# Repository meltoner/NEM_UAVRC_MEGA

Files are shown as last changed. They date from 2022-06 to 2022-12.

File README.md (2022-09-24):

# NEM UAVRC MEGA

NEM Unmanned Vehicle Remote Controlled software on Arduino Mega 2550 pro

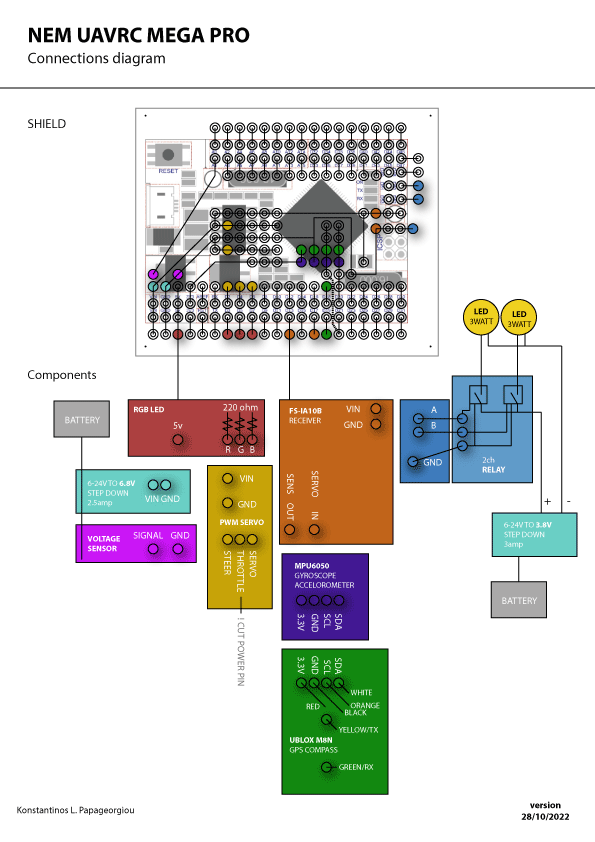
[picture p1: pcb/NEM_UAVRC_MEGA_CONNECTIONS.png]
Shield diagram


## Software Features :

- Software utilises an MPU6050, GPS, Servo, ESC, magnetometer and an amphidromous remote control, powered by an Arduino mega pro.
- Sensors and actuators are all in classes
- Implement seven tasks execution frequencies
- Adaptive steering based on target degrees
- Boots ESC motor and applies a non liner transfer function to the speed remote input
- Computes degrees heading at boot time, used as an offset for the MPU degree heading
- Derives distance and degrees from a target GPS LAT LOT
- Return to target GPS / home on signal loss or switch D
- Adaptive speed while approaching target
- Detection of low battery and return to home
- Transmits distance of vehicle from target GPS
- Lowers throttle while turning
- RGB Led indicator - no GPS red, GPS lock - green, return to home blue
- Variable led blinking indicator
- Target GPS restoration, after power loss

## Hardware

Sensors :

- GPS : [Ublox M8N with compass](https://www.aliexpress.com/item/4001267138914.html)
- Magmetometer : M8n's HMC5883
- MPU : [MPU6050](https://www.aliexpress.com/item/32340949017.html)
- Receiver  [flysky F9-ia10b](https://www.aliexpress.com/item/1005002151189775.html)
- Voltage sensor 0-25v [MH-electronic](https://www.hellasdigital.gr/electronics/sensors/current-sensors/voltage-sensor-module-for-robot-arduino-dc-0-25-v/)

Components : 

- [Arduino mega pro 2560](https://www.aliexpress.com/item/1005002828018807.html)
- Transmitter [flysky FS-I6X](https://www.aliexpress.com/item/1005002086903692.html)
- DC to DC Step down [3 amp](https://grobotronics.com/dc-dc-step-down-1.3-35v-3a.html)
- DC to DC Step down ultra small [2.5 amp](https://www.aliexpress.com/item/32880983608.html)
- Solid state 2 channel relay [SSR 5V 2A - 2 Channel](https://grobotronics.com/relay-module-ssr-5v-2a-2-channel.html)
- High Power Led 3W - [Cold White](https://grobotronics.com/high-power-led-3w-cold-white-emitter-2.html)
- High Power Led 3W - [Green](https://grobotronics.com/high-power-led-3w-green-emitter-2.html)
- RGB LED [anode](https://grobotronics.com/led-clear-5mm-rgb-common-anode.html)
- 3X 220Ohm [resistance](https://grobotronics.com/resistor-1-4w-metal-1-220ohm.html)
- [NEM Battery LI-PO 7.4v 2500mAh](http://www.nemhobby.com/nem-li-po-7-4v-2500mah-20c-500-charges-p31134.html)
- [Male Pin headers](https://grobotronics.com/pin-header-1x40-male-2.54mm-black-long-centered.html)
- [Female Pin headers](https://grobotronics.com/pin-header-1x10-female-2.54mm.html)
- [Cable with compatible JST BEC](http://www.nemhobby.com/plug-extension-silicone-wire-10cm-with-jst-gold-connectors-male-p34787.html)
- [XT60 Gold Connectors - Set](http://www.nemhobby.com/xt60-gold-connectors-set-p32855.html)
- [T-Plug Gold Connector - Male](http://www.nemhobby.com/t-plug-gold-connector-male-p34785.html)
- [Ribbon cable](https://grobotronics.com/ribbon-cable-28awg-0.081mm2-14-wire.html)
- Red, black wire
- PCB Etching agent
- [1mm drills](https://www.ergaleiogatos.gr/shop/trypania-sidirou-hss-bluespot-set-10-temachion/)
- [Copper plate](https://grobotronics.com/prototyping-copper-board-100x75mm-0.8mm-35um-2-layer.html)
- [pilot marker](https://goniasou.gr/pilot-markadoros-anexitilos-twin-marker-begreen/)
- NEM PCB Shield

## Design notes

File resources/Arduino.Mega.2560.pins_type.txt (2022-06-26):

Analog pin 0
Analog pin 1
Analog pin 2
Analog pin 3
Analog pin 4
Analog pin 5
Analog pin 6
Analog pin 7
Analog pin 8
Analog pin 9
Analog pin 10
Analog pin 11
Analog pin 12
Analog pin 13
Analog pin 14
Analog pin 15
Digital pin 0 (RX0)
Digital pin 1 (TX0)
Digital pin 2 (PWM)
Digital pin 3 (PWM)
Digital pin 4 (PWM)
Digital pin 5 (PWM)
Digital pin 6 (PWM)
Digital pin 7 (PWM)
Digital pin 8 (PWM)
Digital pin 9 (PWM)
Digital pin 10 (PWM)
Digital pin 11 (PWM)
Digital pin 12 (PWM)
Digital pin 13 (PWM)
Digital pin 14 (TX3)
Digital pin 15 (RX3)
Digital pin 16 (TX2)
Digital pin 17 (RX2)
Digital pin 18 (TX1)
Digital pin 19 (RX1)
Digital pin 20 (SDA)
Digital pin 21 (SCL)
Digital pin 22
Digital pin 23
Digital pin 24
Digital pin 25
Digital pin 26
Digital pin 27
Digital pin 28
Digital pin 29
Digital pin 30
Digital pin 31
Digital pin 32
Digital pin 33
Digital pin 34
Digital pin 35
Digital pin 36
Digital pin 37
Digital pin 38
Digital pin 39
Digital pin 40
Digital pin 41
Digital pin 42
Digital pin 43
Digital pin 44 (PWM)
Digital pin 45 (PWM)
Digital pin 46 (PWM)
Digital pin 47
Digital pin 48
Digital pin 49
Digital pin 50 (MISO)
Digital pin 51 (MOSI)
Digital pin 52 (SCK)
Digital pin 53 (SS)

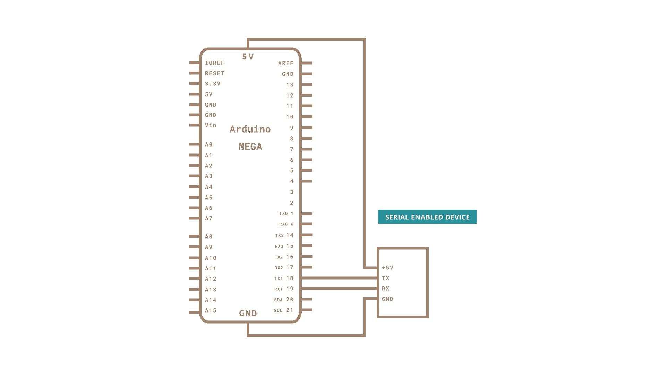
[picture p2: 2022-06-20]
resources/mega_serials_schematic.png

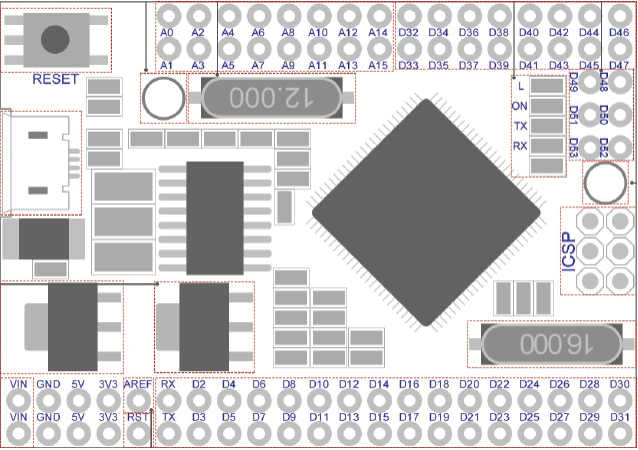
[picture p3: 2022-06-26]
pcb/arduino_mega_2550_pro_$3dm$Embedded$_6498F50D.png

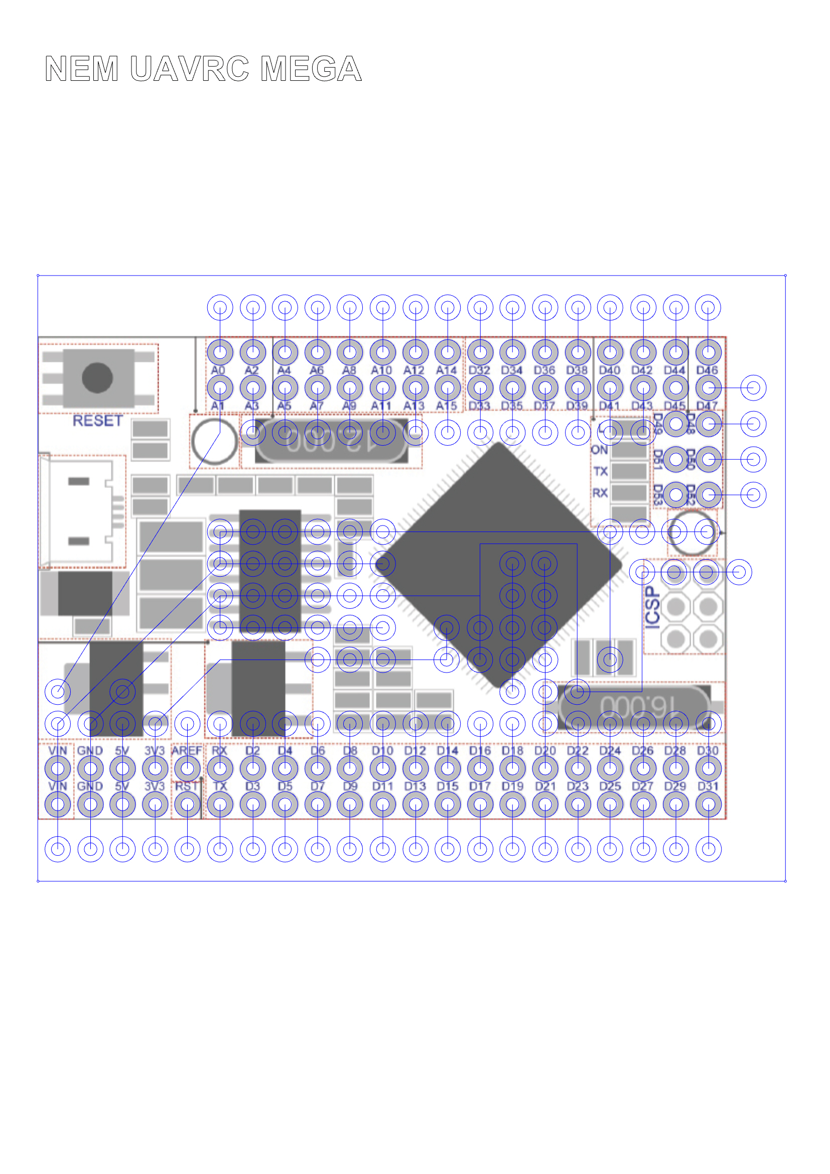
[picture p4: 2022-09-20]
pcb/pcb.jpg

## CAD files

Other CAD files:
pcb/NEM_UAVRC_MEGA_shield_holes.3dm

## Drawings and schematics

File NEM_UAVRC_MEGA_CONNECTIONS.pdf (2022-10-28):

## SHIELD

# NEM UAVRC MEGA PRO

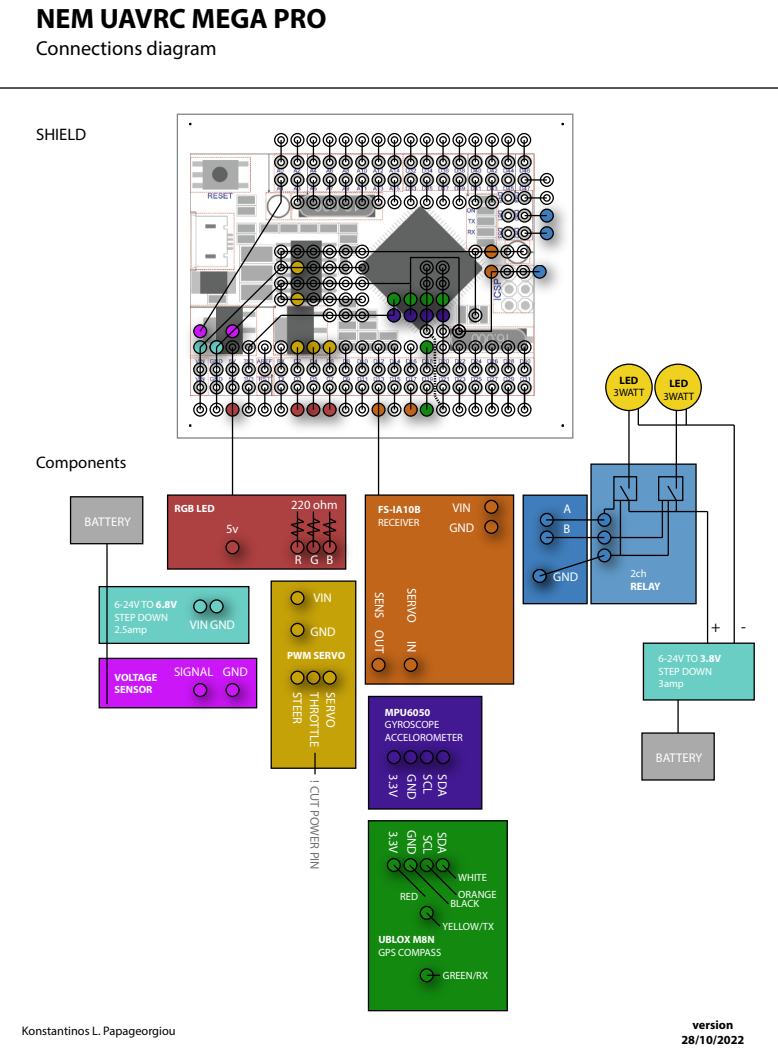
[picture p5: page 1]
RGB LED; 220 ohm; VIN; SIGNAL; OUT; LED 3WATT; GND; SCL; SDA; SENS; SERVO; BATTERY; Components; Connections diagram; STEER; 6-24V TO 6.8V STEP DOWN 2.5amp; VOLTAGE SENSOR; MPU6050 GYROSCOPE ACCELOROMETER; PWM SERVO; FS-IA10B RECEIVER; UBLOX M8N GPS COMPASS; 6-24V TO 3.8V STEP DOWN 3amp; ORANGE BLACK; YELLOW/TX; GREEN/RX; RED; WHITE; 2ch RELAY; version 28/10/2022 Konstantinos L. Papageorgiou

THROTTLE ! CUT POWER PIN

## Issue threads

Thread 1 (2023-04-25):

Firmware for flysky

infernos90, 2023-04-25:
Hello, is it necesary to flash a specific firmware for flysky?
Is it posible to save a waypoints from transmitter?

meltoner, 2023-04-25:
Hi we do not use a specific firmware for flysky. we use as from the factory.
you can save one way point from the transmitter.

infernos90, 2023-04-30:
I know I'm annoying but I apologize.  I am excited about your project and would like to know if you can help me adapt it for a bait boat.  I would like to know if you can modify the arduino code so that you save 2-3 gps coordinates and when the boat gets there it executes a servo open command.  thank you and much respect.

infernos90, 2023-04-30:
Something like this https://youtu.be/YnJC4XFGN8c

meltoner, 2023-04-30:
Sure you can modify the code since it already includes how to reach one target. Interchanging the existing target with an array would be the key modification. how would you enter the gps coords? currently the logic is to get feadback from the gps so you know you have reached the target position and then you can open the bait.

infernos90, 2023-04-30:
"how would you enter the gps coord?"
No. It is possible to save from transmitter? Exemple when i riched the specific point, switch button channel 8 to save it?

meltoner, 2023-05-01:
Well that how its currently done. It first derives the starting point on boot up, but you can update home using the switch.
Do you have some island you want to avoid and you need multiple ?

infernos90, 2023-05-01:
For bait boat is necesary to save one home point and  few waypoints (2-3 is enough). Another question is if it possible to return the boat constantly without this pause for searching gps.

meltoner, 2023-05-01:
inferno anything is possible. feel free to expand the code at your convenience

infernos90, 2023-05-01:
first i need to learn c++... I am good only on soldering and building things... Thanks

meltoner, 2023-05-01:
i see inferno, maybe in the future i wont have so many in my plate and i could do it for you, or you may soon be in a position to do it! talk again!

infernos90, 2023-05-01:
Ok. Thanks. I subscribed you!

oldcityboy, 2024-10-12:
> Yem botu için bir ev noktası ve birkaç rota noktası (2-3 yeterlidir) kaydetmek gerekir. Bir diğer soru ise gps araması için bu duraklama olmadan botu sürekli döndürmenin mümkün olup olmadığıdır.

Hello, have you installed GPS autopilot and location marking inside the feeding boat?

meltoner, 2024-10-13:
have a read at the documentation

Closed 2023-04-25.

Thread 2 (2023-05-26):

Brushless ESC

infernos90, 2023-05-26:
Hello again. This work with brushless ESC?

meltoner, 2023-05-26:
yep

infernos90, 2023-05-26:
I was unable to arm the motor.

meltoner, 2023-05-26:
can you send me a picture of what you have done?

meltoner, 2023-05-26:
I would guess that maybe your connections are wrong, or the pin was set incorrectly.
For your info, the arm command is visible within the Throttle::setup(Context &_context) function see lines 18 and 19.
If you still have issues the best approach is to make a hello world example that only arms the motor and then spins it. once you achieve that you ll be able to see what was out of place in your code currently.

infernos90, 2023-05-26:
>

I assambled everything to a testing board. Tomorrow i will soldering everything and testing again. This part " (byte pin){
  _pin = pin;" from the code, is attributing automatically pin for every component

meltoner, 2023-05-26:
yes Throttle is parametrised on its pin, on UAVRC_MEGA.ino on line 33 you see Throttle throttle(2); this means that the esc should be put on D2

infernos90, 2023-05-26:
Ok, i understand.
What is the role of the "hook" in this project?

meltoner, 2023-05-26:
for fishing, drops the hook

infernos90, 2023-05-26:
What switch is for activating the hook?

vin., 26 mai 2023, 23:27 meltoner ***@***.***> a scris:

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

meltoner, 2023-05-26:
give it a try to find it on your own, you would search where the object hook is used.
if you can't find it, ill check it out for you

infernos90, 2023-05-27:
Switch B!

meltoner, 2023-05-27:
bravo inferno90 !

infernos90, 2023-05-27:
Look at this video. Only beeping from ESC and not arming.

https://youtu.be/g7Y91y6uPNA

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

meltoner, 2023-05-28:
nice work !!

i noticed that you haven't actually connected the esc to the board. it should be connected to the arduino instead of the flysky receiver have a look at some more detailed photos of the fabrication in the attached pdf.

its flysky -> arduino -> esc, servo
 (see the horizontal ibus cable (in,out) do slot them in the vertical slots)

[phase2_prototype_fabrication.pdf](https://github.com/meltoner/NEM_UAVRC_MEGA/files/11584009/phase2_prototype_fabrication.pdf)

In case its helpful i had also made a board like a shield so you can detach the whole thing. Although it may not be that obvious the first image in the repository shows the "board".

I also understand that you have went to assemble everything in one go, which is also what i usually do and then get a hell of debugging in view of one just error. the proper way to do it is incrementally, i.e. first verify X then verify y and etc. i also noticed that you are using a regular led instead of an rgb. off course its not mandatory.

just take it step by step and it would also be very helpfull to also use the serial cable to print out on terminal the various phases the board undergoes during initialization.

since you have made this progress i am confident you with few careful iterations you reach the desired goal.

insane work! bravo

infernos90, 2023-05-28:
Maybe you didn't see correctly, but ESC is connected to pin D2. In the video i changed ESC connection to pin D2, D4 și D6 and not arming....

meltoner, 2023-05-28:
mmm yes, i see in the video its different from the photos.
1. note that the arm can happen if the motor takes power and the arduino takes power simultaneously. arming happens within the first power up.

2 what about the other stuff, does the servo move while connected to d4, i didn't see a movement in the video ?
3 how about if you connect a usb to read up the serial? context.apply(); prints out almost all internal details, so you can see can checkout what work and what doesn't work.
4. having done 3 you can also add in the setup function of each module a print like Serial.print("setting up mpu"); so you can see if something fails which would pauses the boot up sequence all together. for example the mpu might say while(mpuisnotacailable); wait until it is.

infernos90, 2023-05-28:
I have fs-ia6b receiver and in your project is fs-ia10b receiver. Maybe it is a problem?

meltoner, 2023-05-28:
probably not, since it has an ibus slots..

do you know how to see the serial print out of the board ? to see whats is happening? as you after you upload the firmware just open up serial from arduino cli

infernos90, 2023-05-28:
![Uploading IMG20230528130155.jpg…]()

infernos90, 2023-05-28:
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

meltoner, 2023-05-28:
ok its should print more after the mpu so something is interrupted, though mpu is after the throttle. in any case

after the mpu its the mag, i see no printout there in its setup, next is hook, ok next is gps. the gps setup function does print Serial.print("setup"); so since i do not see it in the print i understand that something before it fails. this apears to be the mag.
```
  mpu.setup(context);           rgb.apply_color(3);  delay(500); // yellow
  mag.setup(context);           rgb.apply_color(4);  delay(500);
  hook.setup(context);  
  gps.setup(context);           rgb.apply_color(5);  delay(500);
  steer.setup(context); 
  battery.setup(context);
  home.setup(context);          rgb.apply_color(6);  delay(500);
  invoker.setup(context);
  relayA.setup(context);
  relayB.setup(context);        context.color = 3;  delay(500);
  remote.setup(context);
  telemetry.setup(context);
```

 Add there in mag more print out to see if it passes from that place. although these are after the throttle pass over everything to ensure all components are setuped properly. At the end of the program setup sequence, its should enter in the loop sequence and every 1 second it should reflect all sensors readings via the context.apply()

infernos90, 2023-05-28:
I connected SCL and SDA from mpu and mag to same pin. It is correct?

meltoner, 2023-05-28:
i think its not. According to the diagram , https://github.com/meltoner/NEM_UAVRC_MEGA/blob/main/pcb/NEM_UAVRC_MEGA_CONNECTIONS.png i see in the green area, that the magnetometer/compass is assigned to an RX pin.

meltoner, 2023-05-28:
the 15th outer pin counting from the left as i see the diagram

infernos90, 2023-05-28:
According to your diagram, SDA from mpu and mag is connected both to pin 20 and SCL from mag and mpu connected both to pin 21

infernos90, 2023-05-28:
> the 15th outer pin counting from the left as i see the diagram

This pin is for gps module  according to your diagram.

meltoner, 2023-05-28:
my gps has a magnetometer embedded. that is why the look as the same module.
in the image the top pins are for the gps and the bottom is for the compass

meltoner, 2023-05-28:
Yes you are correct, as you stated above. gps uses the serial the mpu and mag use sda and scl. checked it out in haste
About how to debug the remedy is to add Serial.print and see where the execution stops to determine where is the problem.
for example you have to find out which was the last module starting to initialize but didn't complete.

infernos90, 2023-05-28:
I found a problem: it shows "begin mpu, do not move, succes" without mpu and mag connected. Only module connected is gps

infernos90, 2023-05-28:
Maybe is a problem with pins adress attribution

meltoner, 2023-05-28:
strange i would expect it to fail without them connected. ..

infernos90, 2023-05-28:
I tried with a simple servo motor. Not working. Maybe is not something correct in code.

meltoner, 2023-05-29:
no everything has been fabricated and tested multiple times with videos. i can't project what is off could be just a wire missed, but one would have to test each thing carefully until discovers what is off. In theory i would test each component you have on its own one by one.

meltoner, 2023-05-29:
inferno it just happens that i will be reproducing a 3rd time the project within the next month, nearly identical setup, so i will be re-passing the same steps you have and in case i find any deviation in the plans ill let you know.

infernos90, 2023-05-29:
Ok. Thank you.

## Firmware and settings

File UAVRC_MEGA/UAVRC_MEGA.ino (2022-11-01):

//
// @author : Konstantinos L. Papageorgiou - 2022 - kp at rei.gr
// @repo: https://github.com/meltoner/NEM_UAVRC_MEGA
//
// # NEM UAVRC MEGA
// 
// NEM Unmanned Vehicle Remote Controlled software on Arduino Mega 2550 pro
//

#include "Context.h"
#include "Invoker.h"

#include "Mag.h"
#include "Gps.h" 
#include "Mpu.h" 
#include "Steer.h"
#include "hook.h"
#include "Throttle.h"
#include "Remote.h"
#include "Telemetry.h"
#include "Home.h"
#include "RGB.h"
#include "Battery.h"
#include "Relay.h"

Context context(0);
Invoker invoker(0);

Mag mag(0);
Gps gps(0);
Mpu mpu(0);

Throttle throttle(2);
Steer steer(4);
Hook hook(6);

Remote remote(0);
Telemetry telemetry(0);

Home home(0);
RGB rgb(0);
Battery battery(0);

Relay relayA(50, 0);
Relay relayB(52, 1);

//-----------------------------------------

void setup() {
  context.setup();  
  rgb.setup(context);
  throttle.setup(context);      rgb.apply_color(1); // green
  delay(3000);                  rgb.apply_color(2); // blue
  
  mpu.setup(context);           rgb.apply_color(3);  delay(500); // yellow
  mag.setup(context);           rgb.apply_color(4);  delay(500); 
  hook.setup(context);          
  gps.setup(context);           rgb.apply_color(5);  delay(500);
  steer.setup(context);         
  battery.setup(context);       
  home.setup(context);          rgb.apply_color(6);  delay(500);
  invoker.setup(context);
  relayA.setup(context);
  relayB.setup(context);        context.color = 3;  delay(500);
  remote.setup(context);        
  telemetry.setup(context);

}

//-----------------------------------------

void apply_interval_0(){
  mag.apply();
  telemetry.apply();
  mpu.apply();
}

void apply_interval_1(){
  remote.apply();
  steer.apply();
  throttle.apply();
}

void apply_interval_2(){
  gps.apply();
  telemetry.run();
  home.apply();
  rgb.apply();
  telemetry.run();
  relayA.apply();
  relayB.apply();  
}

void apply_interval_3(){
  context.apply();
  hook.apply();
}

void apply_interval_4(){
  relayA.toggle();
}

void apply_interval_5(){
  battery.apply();
}

void apply_interval_6(){
  if(context.toHomeActive)
    mag.updateMagOffset();

  gps.testStationary();
}

void apply_interval_7(){
  home.bursts();
}


//-----------------------------------------

void run_invoker(int i){
    switch(i){
      case 0: apply_interval_0(); break;
      case 1: apply_interval_1(); break;
      case 2: apply_interval_2(); break;
      case 3: apply_interval_3(); break;
      case 4: apply_interval_4(); break;
      case 5: apply_interval_5(); break;
      case 6: apply_interval_6();break;
      case 7: apply_interval_7();break;
      case 100: break;
    }
}

//-----------------------------------------

void loop(){
  mpu.update();
  telemetry.run();
  int actionIndex = invoker.apply();
  while(actionIndex != 100){
    run_invoker(actionIndex);
    telemetry.run();
    actionIndex = invoker.apply();
  } 
}

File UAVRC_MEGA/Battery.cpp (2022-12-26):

/*
  Battery.h - Library for warping the functions controlling the Battery power levels
  Author - Konstantinos Papageorgiou kp at rei.gr 2022 
*/

#include "Arduino.h"
#include "Battery.h" 
#include "Context.h"

Battery::Battery(byte pin){}

void Battery::setup(Context &_context){
  context = &_context;
  measureVoltage();

  

  apply();  
}

float Battery::measureVoltage(){
  context->voltage =  (analogRead(0) / 40.92);
  context->voltage = context->voltage * 0.735 ;
  return context->voltage;
}

void Battery::apply(){
  measureVoltage();
  // battery cell detection based on single cell min (3.54), max (4.2) multiples
  for(cells = 1;cells < 6;cells++){
    if((cells * minV) > context->voltage ){
      cells--;
      break;
    }
  }
  // derive how close we are to the min voltage based on the number of cell
  context->capacity = (byte)( ((context->voltage - (cells * minV)) / (context->voltage - (cells * maxV))) * 100 ); 
  context->isLowBattery = context->voltage < (cells * minV);
}


// testing at 7.4 volt power supply
// 
// 1.1 watt at rest
// 4 wat wi servo activated
// 8.8 watt with lights only active
// 10 watt lights and servo 
// 6-15 watt mottors only
// 26 watt - full throtle, lights and servo

// example to rectify the voltage using a power bench and linear regression.
// removed as for some reason this problem apeared only once, and the consequent day all readings were fine.
// 

// on latest state we read 8.26v insted of 7.5v
// correlating readings with voltagemeter 

  // 15 12.6
  // 12 10.75
  // 10 9.65
  // 8 8.5
  // 7.5 8.35
  // 7.3 8.4 
  // 7.2 8.3
  // 7.1 8.20
  // 7   8.16
  // 6.9 8.13
  // 6.8 8.06
  // 6.7 8.01
  // 6.6 7.9- 8.11 


// library(data.table)
// measurement <- data.table(
//   x = c( 8.5, 8.4, 8.3, 8.20, 8.16, 8.13, 8.06, 8.01, 7
//   y = c(  8,  7.3, 7.2, 7.1, 7, 6.9, 6.8, 6.7, 6.6)
// )
// fit <- lm(y~x, data = measurement)
// summary(fit)
// 
// adapt <- function(x)
//  -9.9030 + x * 2.0734
// 
// measurement[, Y := adapt(x)]
// x = sensor y = actual Y = predicted by the linear regression
//     x   y        Y
// 1: 8.50 8.0 7.720900
// 2: 8.40 7.3 7.513560
// 3: 8.30 7.2 7.306220
// 4: 8.20 7.1 7.098880
// 5: 8.16 7.0 7.015944
// 6: 8.13 6.9 6.953742
// 7: 8.06 6.8 6.808604
// 8: 8.01 6.7 6.704934
// 9: 7.90 6.6 6.476860

// context->voltage = -9.9030 + context->voltage * 2.0734;

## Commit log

2022-06-20 Add files via upload
    arduino mega 2560 pro pin out diagram
2022-06-20 Add files via upload
    Initial fork from https://github.com/meltoner/NEM_UAVRC_LEONARDO
    focus on utilising the additional serial ports of arduino mega to submit data to the remote controller
    [Battery.cpp, Context.cpp, Context.h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]
2022-06-20 Add files via upload
    aiming to utilize the additional Serial port of arduino mega to submit data to the remote controller
    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
    [Battery.cpp, Context.cpp, Context.h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]
2022-06-26 Add files via upload
    IBUs searching for transmitting sensors to the remote screen
2022-06-26 Add files via upload
    arduino mega pins - to sensors connections
2022-06-26 Add files via upload
    Arduino mega pins out
2022-06-26 Add files via upload
    flysky telemetry - sensors submission verified
2022-06-30 compile project and upload in arduino
2022-06-30 shield connecting to arduino 3d model
    [mega_pro_uavrcboard.3dm, mega_pro_uavrcboard.stl]
2022-07-06 components connectivity with images
    RGB grd to +5v fix
2022-07-07 extending with an RGB led light
2022-07-10 connect receiver on Vin than in 5v
    that will allow to see the battery voltage in the transmitter.
2022-09-20 Add files via upload
    pcb drilling holes
2022-09-24 Add files via upload
    updated version pcb
2022-10-02 relay fix
    solid state relays work with ac instead dc. replaced with regular relays
2022-10-02 relay fix
2022-10-30 change of pcb - recheck phases
    Fix on gps wires and in diagram : revision 28/10/2022
    Better rgb light control, signals while setting up each module.
    RGB blinking save power
    Many iterations on the stability of telemetry.
    Adaptations on low battery detection.
    Testing home detection and return to home
    Change home setting - from number of satellites and after time period to
    detecting stationary with 10 seconds steps.
    Fix on return to home when home hasn't been set.
    More iterations on the stability of telemetry.
    low battery detection needs further validation
    telemetry is better but not perfect
    gps remains with the usual responsiveness
    the relay could go before the power adapter if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
    [Battery.cpp, Context.cpp, Context.h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]
2022-10-30 Add files via upload
    move gps second part as 2 and 3 sensors and their first part as 4 and 5th
2022-12-26 cell battery detection and capacity determination
2022-12-26 always derive the number of battery cells
